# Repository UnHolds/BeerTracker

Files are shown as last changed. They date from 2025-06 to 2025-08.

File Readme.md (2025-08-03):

# Beer Tracker

This repository contains the PCB, Enclosure and Code for the Beer Tracker.

The Beer Tracker allows a group of people to keep track of
various things (mainly beer).

## What does it do?

Each person gets a tracker. If a person logs a drink then the
total amount will be synced between all peers (if in reach).
If a peer is out of reach, it will be synced later. (It can
also sync via multiple hops: eg A syncs data to B and B syncs
As data to C).

The device also allows the user to see the current counts of
the other peers.

## Why?

This is a really good question...

It all started during a music festival, where we tracked our
beer consumption with a tally sheet. This worked great, as
long as we all are together in a group. But some people have
different music taste and hence the group was split and the
tracking failed. This major problem needed to be addressed. A
smart way to solve it would be to just you a tracking app, or
to write our own app if we are really fancy. But those
solutions aren't enough overengineered!!!. Hence we created
this project.

## Structure

- `code` - source code for the ESP32
- `enclosure` - STL files and FreeCAD files of the case
- `kicad` - schematic + pcb layout

## Images

TODO

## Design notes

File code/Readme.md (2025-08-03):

# Code

Welcome to the brain section of the project.

## Config

There exists the `config.h` file. Here you can define:
- Number of users and their names
- Max username length
- Sleep time (time between auto-syncs)

The type of things to be tracked are somewhat hardcoded and can't be changed that easily. That's a bit sad, but it can't be helped. This may be changed in the future.

## Structure

- `button` - handles IO events of 1 button
- `display` - everything that is displayed and menu stuff
- `input` - handles IO (single press, double press, long press)
- `main` - inits everything and then loops
- `message` - handles the send and recv of the sync messages

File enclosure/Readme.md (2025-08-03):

# Enclosure

Welcome to the enclosure section of the beer tracker. This enclosure can be
made via a 3D printer. I recommend NOT using PLA, but rather PETG or ASA.
The enclosure will be more robust this way.

If you just want to print it and not modify it, then you can use the provided
STL files located in the `stl` folder. (Yes you need to print all 3).

If you want to modify the files you can open the projectfile (`BeerTracker.FCStd`)
with FreeCAD.

## Additional Material

- 4x M3 Screws
- 4x M3 Nuts

## 3D - Assembly

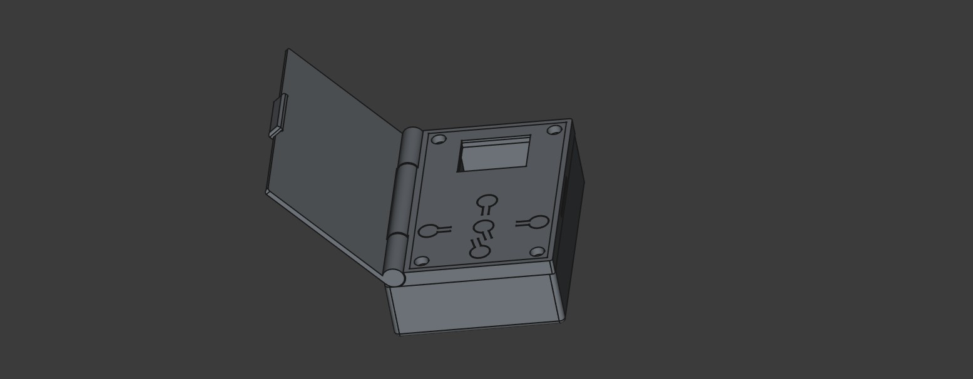
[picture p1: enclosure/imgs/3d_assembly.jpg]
Assembly of the enclosure


## How to assemble

1. Insert the button cover inside the lid.
2. Insert the nut into the case from the bottom. (Make sure that nut is oriented correctly,
    - Tip: If you have a longer M3 screw, then insert it from the top of the case and then screw on the nut. After that you can use a hammer to insert the nut from the bottom. The screw will keep the nut straight.)
3. Insert the PCB into the button cover.
4. Sandwich the two halfs
5. Done.

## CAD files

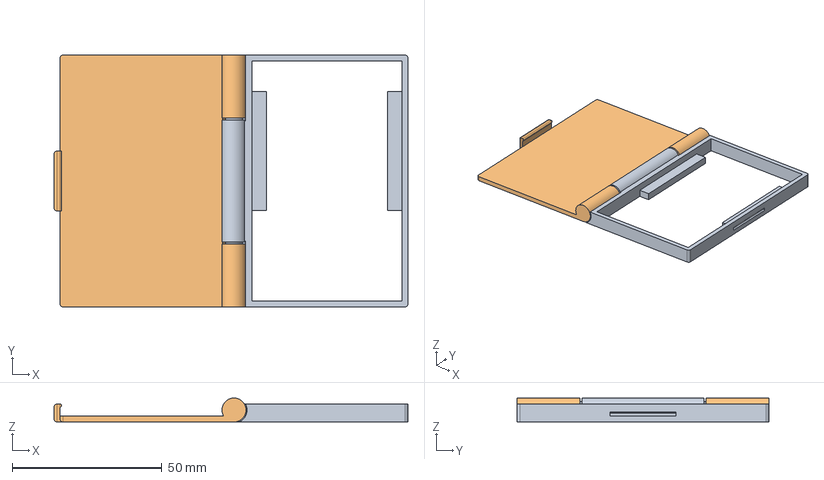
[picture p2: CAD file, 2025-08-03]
enclosure/BeerTracker.FCStd
118.0 x 84.0 x 8.00 mm
TopBottom
TopTop

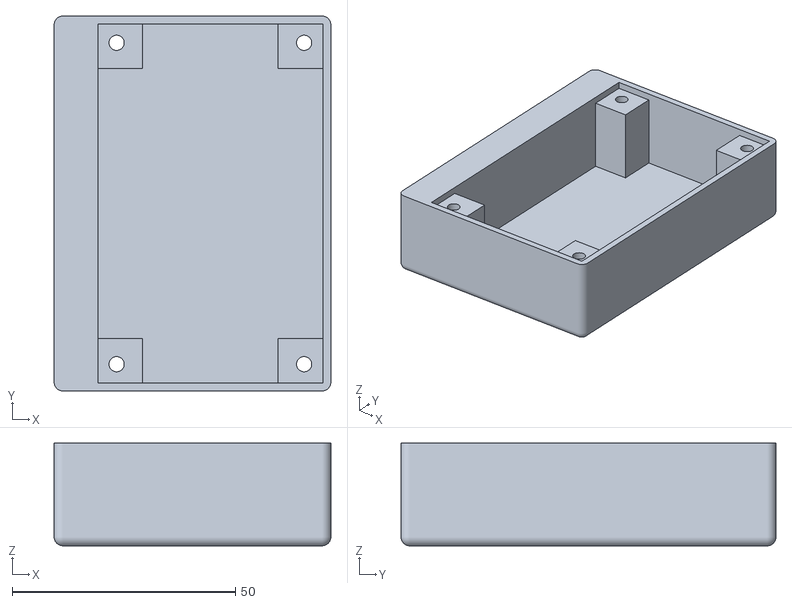
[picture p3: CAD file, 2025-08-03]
enclosure/stl/lower_case.stl
62.0 x 84.0 x 23.0

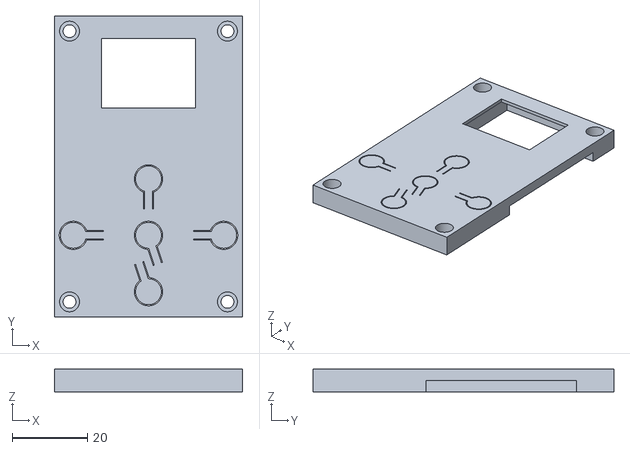
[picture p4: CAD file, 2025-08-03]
enclosure/stl/btn_cover.stl
50.0 x 80.0 x 6.00

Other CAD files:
enclosure/stl/lid.stl

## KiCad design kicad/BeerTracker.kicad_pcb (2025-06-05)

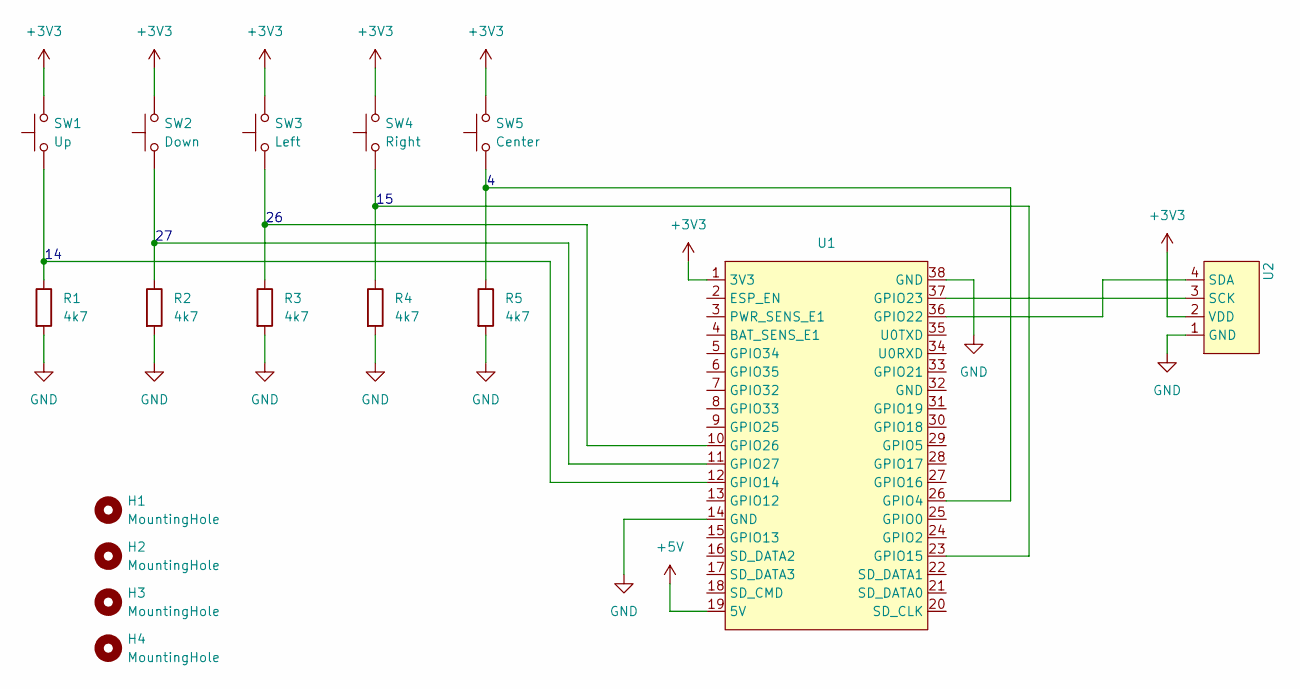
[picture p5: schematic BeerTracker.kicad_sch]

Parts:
H1, H2, H3, H4: MountingHole; MountingHole_3.2mm_M3
R1, R2, R3, R4, R5: 4k7; R_0805_2012Metric_Pad1.20x1.40mm_HandSolder
SW1: Up; SW_PUSH_6mm
SW2: Down; SW_PUSH_6mm
SW3: Left; SW_PUSH_6mm
SW4: Right; SW_PUSH_6mm
SW5: Center; SW_PUSH_6mm
U1: ESP32-DevKit-LiPo
U2: OLED

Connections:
+3V3: SW1.2, SW2.2, SW3.2, SW4.2, SW5.2, U1.1 (3V3), U2.2 (VDD)
+5V: U1.19 (5V)
GND: R1.2, R2.2, R3.2, R4.2, R5.2, U1.14 (GND), U1.38 (GND), U2.1 (GND)
unnamed: R5.1, SW5.1, U1.26 (GPIO4)
unnamed: R1.1, SW1.1, U1.12 (GPIO14)
unnamed: R4.1, SW4.1, U1.23 (GPIO15)
unnamed: U1.36 (GPIO22), U2.4 (SDA)
unnamed: U1.37 (GPIO23), U2.3 (SCK)
unnamed: R3.1, SW3.1, U1.10 (GPIO26)
unnamed: R2.1, SW2.1, U1.11 (GPIO27)

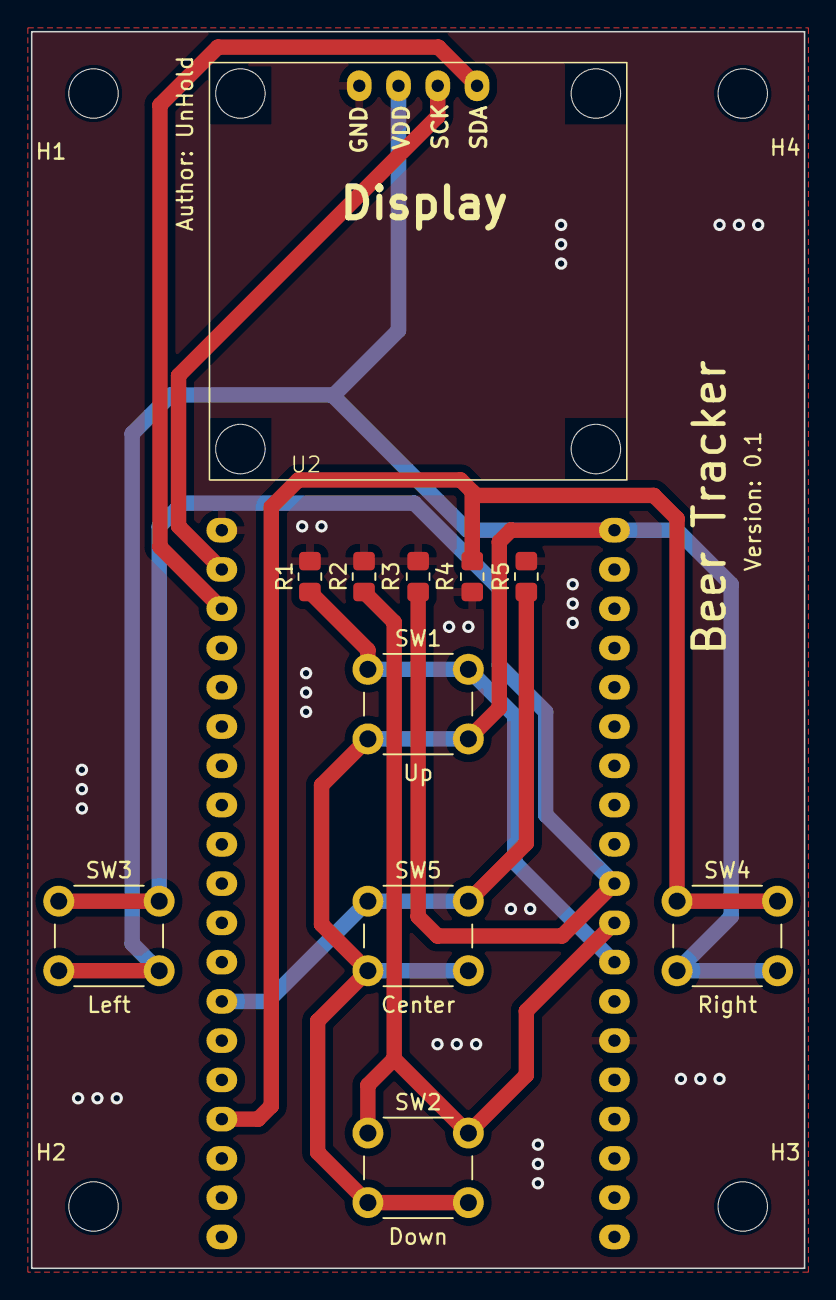
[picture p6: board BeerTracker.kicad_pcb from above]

Board: 2 copper layers, 50.0 x 80.0 mm, 16 parts (1 on the bottom side), 9 nets.

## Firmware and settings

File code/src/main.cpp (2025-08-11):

#include <Arduino.h>
#include <Wire.h>
#include <ESP32Time.h>

#include "display.h"
#include "input.h"
#include "message.h"
#include "config.h"
#include "peers.h"


#define SCREEN_WIDTH 128 // OLED display width, in pixels
#define SCREEN_HEIGHT 64// OLED display height, in pixels
#define SDA_SCREEN 22
#define SCK_SCREEN 23
#define OLED_RESET -1 // Reset pin

ESP32Time rtc(0);


Display display(SCREEN_WIDTH, SCREEN_HEIGHT, VERSION, &rtc);
Input input(14, 27, 26, 15, 4, true);

Message message;

unsigned long update_send_time = ULONG_MAX;
unsigned long update_sleep_time = ULONG_MAX;
bool timer_wakeup;
bool screen_locked = true;
int screen_lock_sequence_idx = 0;
InputType unlock_sequence[] = {InputType::LEFT, InputType::RIGHT, InputType::LEFT, InputType::RIGHT};

#ifdef DEBUG
String InputTypetoString(InputType type) {
    switch (type) {
        case InputType::UP:
            return "UP";
        case InputType::DOWN:
            return "DOWN";
        case InputType::LEFT:
            return "LEFT";
        case InputType::RIGHT:
            return "RIGHT";
        case InputType::CENTER:
            return "CENTER";
        case InputType::UP_LONG:
            return "UP_LONG";
        case InputType::DOWN_LONG:
            return "DOWN_LONG";
        case InputType::LEFT_LONG:
            return "LEFT_LONG";
        case InputType::RIGHT_LONG:
            return "RIGHT_LONG";
        case InputType::CENTER_LONG:
            return "CENTER_LONG";
        case InputType::UP_DOUBLE:
            return "UP_DOUBLE";
        case InputType::DOWN_DOUBLE:
            return "DOWN_DOUBLE";
        case InputType::LEFT_DOUBLE:
            return "LEFT_DOUBLE";
        case InputType::RIGHT_DOUBLE:
            return "RIGHT_DOUBLE";
        case InputType::CENTER_DOUBLE:
            return "CENTER_DOUBLE";
        case InputType::NONE:
            return "NONE";
        default:
            return "UNKNOWN_INPUT_TYPE"; // Fallback for any unhandled or future enum values
    }
}
#endif

void go_to_sleep() {
    long time_till_next_wakeup = SLEEP_TIME - rtc.getEpoch() % SLEEP_TIME;
    #ifdef DEBUG
    Serial.print("Timer sleeping for: ");
    Serial.println(time_till_next_wakeup);
    Serial.print("Wakeuptime: ");
    Serial.println(rtc.getEpoch() + time_till_next_wakeup);
    #endif
    esp_sleep_enable_timer_wakeup(secToUs(time_till_next_wakeup));
    display.clear();
    esp_deep_sleep_start();
}

void send_update_message() {
    #ifdef DEBUG
    Serial.println("Sending update message");
    #endif
    message.send();
}


void add_peers(){
    message.add_peers(peers, NUMBER_OF_PEERS);
}


long last_command = millis();

void handle_unlock_event(InputType t){

    if(t == unlock_sequence[screen_lock_sequence_idx]){
        screen_lock_sequence_idx++;
    }else{
        screen_lock_sequence_idx == 0;
    }

    if(screen_lock_sequence_idx == sizeof(unlock_sequence) / sizeof(unlock_sequence[0])){
        screen_locked = false;
        screen_lock_sequence_idx = 0;
    }
}

void setup() {

    screen_locked = LOCK_SCREEN_ENABLE;

    esp_sleep_wakeup_cause_t wakeup_reason = esp_sleep_get_wakeup_cause();

    Serial.begin(115200);
    Wire.begin(SDA_SCREEN, SCK_SCREEN);

    if (!LittleFS.begin(true)) {
        Serial.println("Formatting LittleFs!!");
        if (!LittleFS.begin()) {
            Serial.println("FATAL: Failed to mount LittleFS even after formatting!");
            return;
        }
    }

    input.begin();
    message.begin(&rtc);

    display.begin(&message);
    if (wakeup_reason != ESP_SLEEP_WAKEUP_TIMER){
        display.splash_screen();
    }

    add_peers();

    #ifdef DEBUG
    switch (wakeup_reason) {
        case ESP_SLEEP_WAKEUP_EXT0:
            Serial.println("Wakeup caused by external signal using RTC_IO");
        break;
        case ESP_SLEEP_WAKEUP_EXT1:
            Serial.println("Wakeup caused by external signal using RTC_CNTL");
        break;
        case ESP_SLEEP_WAKEUP_TIMER:
            Serial.println("Wakeup caused by timer");
        break;
        case ESP_SLEEP_WAKEUP_TOUCHPAD:
            Serial.println("Wakeup caused by touchpad");
        break;
        case ESP_SLEEP_WAKEUP_ULP:
            Serial.println("Wakeup caused by ULP program");
        break;
        default:
            Serial.printf("Wakeup was not caused by deep sleep: %d\n", wakeup_reason);
        break;
    }
    #endif

    if(wakeup_reason == ESP_SLEEP_WAKEUP_TIMER){
        update_send_time = millis() + (UPDATE_AWAKE_TIME - USER_SEND_OFFSET * NUM_USER) / 2 + USER_SEND_OFFSET * message.current_user_idx();
        update_sleep_time = millis() + UPDATE_AWAKE_TIME;
        timer_wakeup = true;
    }else{
        update_send_time = ULONG_MAX;
        update_sleep_time = ULONG_MAX;
        timer_wakeup = false;
    }

    #ifdef DEBUG
        Serial.print("current epoch: ");
        Serial.println(rtc.getEpoch());
    #endif

    last_command = millis();

    if(screen_locked && wakeup_reason != ESP_SLEEP_WAKEUP_TIMER) {
        display.lock_screen();
    }

    //fixes input on startup
    input.get_input();
}



void loop() {

    long current_millis = millis();
    InputType t = input.get_input();
    if(t != InputType::NONE) {
        last_command = current_millis;
        timer_wakeup = false;
        #ifdef DEBUG
        Serial.println(InputTypetoString(t));
        #endif
    }

    if(current_millis - last_command > STANDBY_TIMEOUT && update_sleep_time == ULONG_MAX){
        #ifdef DEBUG
            Serial.println("Going to sleep standby timeout");
        #endif
        go_to_sleep();
    }

    if(timer_wakeup == false){

        if(screen_locked){
            handle_unlock_event(t);
            if(screen_locked){
                //still locked return
                return;
            }
        }

        display.update(t);
    }

    //send update msg
    if(current_millis > update_send_time){
        send_update_message();
        update_send_time = ULONG_MAX;
    }

    //goto sleep
    if(current_millis > update_sleep_time){
        #ifdef DEBUG
            Serial.println("Going to sleep after update");
        #endif
        update_sleep_time == ULONG_MAX;
        go_to_sleep();
    }
}

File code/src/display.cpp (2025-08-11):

#include "display.h"

Display::Display(int width, int heigth, const char* version, ESP32Time* rtc) : display(width, heigth, &Wire, -1) {
    this->width = width;
    this->height = height;
    this->version = version;
    this->rtc = rtc;
}

void Display::begin(Message* message) {
    if(!this->display.begin(SSD1306_SWITCHCAPVCC, 0x3C)) {
        Serial.println(F("SSD1306 allocation failed"));
        for(;;);
    }
    this->display.clearDisplay();
    this->message = message;

    pinMode(BAT_PIN, INPUT);
    pinMode(PWR_PIN, INPUT);

    if((&this->message->send_message)->time > rtc->getEpoch()){
        #ifdef DEBUG
        Serial.println("updating the epoch to the time stored at esp32");
        #endif
        this->rtc->setTime((&this->message->send_message)->time, 0);
    }
}

void Display::print_x_y(String text, int x_pos, int y_pos, int text_size) {
    this->display.setTextSize(text_size);
    this->display.setTextColor(WHITE);
    this->display.setCursor(x_pos, y_pos);
    this->display.println(text);
}

void Display::print_center_x(String text, int y_pos, int text_size) {
    this->display.setTextSize(text_size);
    this->display.setTextColor(WHITE);
    this->display.setCursor((this->width / 2) - (6 * text_size * text.length() / 2), y_pos);
    this->display.println(text);
}

void Display::splash_screen() {

    this->print_center_x("Beer-Track", 10, 2);
    this->print_center_x("by @UnHold", 30, 1);
    std::string buf("Version: ");
    buf.append(this->version);
    this->print_center_x(buf.c_str(), 45, 1);

    #ifdef COMMIT_HASH
    std::string buf2("(");
    buf2.append(COMMIT_HASH);
    buf2.append(")");
    this->print_center_x(buf2.c_str(), 55, 1);
    #endif

    this->display.display();
    delay(SPLASH_SCREEN_TIME);
    this->display.clearDisplay();
    this->display.display();
}

void Display::print_battery() {
    char bat_v[6];
    float pwr = 3.3 / 4095.0 * analogRead(PWR_PIN);
    float bat = 3.3 / 4095.0 * analogRead(BAT_PIN);

    if(pwr > 2){

        this->print_x_y("PWR", this->width - 6 * 3, 0, 1);
    } else {
        this->print_icon(Icon::BAT, 128-8, 8/2);
        //snprintf (bat_v, sizeof(bat_v), "%.2fVV", bat);
        //this->print_x_y(bat_v, this->width - 6 * (sizeof(bat_v)), 0, 1);
    }
}

void Display::lock_screen(){
    this->clear();
    this->print_icon(Icon::LOCKED, 64, 20);
    this->print_center_x("To Unlock: < > < >", 42, 1);
    this->display.display();
}

void Display::print_time() {
    char time_str[32];
    // 2024-06-27 23:24:25
    sprintf(time_str, "%04d-%02d-%02d %02d:%02d:%02d", rtc->getYear(), rtc->getMonth(), rtc->getDay(), rtc->getHour(true), rtc->getMinute(), rtc->getSecond());
    this->print_center_x(time_str, 64-7, 1);
}
void Display::print_icon(Icon icon, int x_pos, int y_pos) {
    int id = static_cast<int>(icon) & 0xFF;
    int y_size = (static_cast<int>(icon) >> 8) & 0xFF;
    int x_size = (static_cast<int>(icon) >> 16) & 0xFF;
    this->display.drawBitmap(x_pos - x_size / 2, y_pos - y_size / 2, icon_array[id], x_size, y_size, WHITE);
}

void Display::update(InputType input) {
    this->display.clearDisplay();
    //print the username in the topleft
    this->print_x_y(this->message->send_message.users[this->message->send_message.user_id].name, 0, 0, 1);
    print_battery();
    print_time();


    switch(this->menu){
        case Menu::MAIN:
            this->update_main_menu(input);
        break;
        case Menu::BEER:
            this->print_center_x("Beer", 0, 1);
            this->increment_menu(input, &this->message->send_message.users[this->message->send_message.user_id].beer);
        break;
        case Menu::SHOT:
            this->print_center_x("Shot", 0, 1);
            this->increment_menu(input, &this->message->send_message.users[this->message->send_message.user_id].shots);
        break;
        case Menu::WATER:
            this->print_center_x("Water", 0, 1);
            this->increment_menu(input, &this->message->send_message.users[this->message->send_message.user_id].water);
        break;
        case Menu::SELECT_USER:
            this->print_center_x("WhoAmI", 0, 1);
            this->change_user(input);
        break;
        case Menu::RESET:
            this->reset(input);
        break;
        case Menu::SHOW_USERS:
            this->print_center_x("Users", 0, 1);
            this->show_users(input);
        break;
        case Menu::SET_TIME:
            this->print_center_x("Set Time", 0, 1);
            this->set_time(input);
        break;
    }

    this->display.display();
}

void Display::change_user(InputType input) {
    if(this->submenu_idx == -1){
        this->submenu_idx = this->message->send_message.user_id;
    }

    //safety
    this->submenu_idx = this->submenu_idx % NUM_USER;

    this->print_center_x(this->message->send_message.users[this->submenu_idx].name, 32 - 8, 2);
    this->print_x_y("<", 10, 32 - 8, 2);
    this->print_x_y(">", 110, 32 - 8, 2);

    if(input == InputType::LEFT){
        this->submenu_idx = (this->submenu_idx + NUM_USER - 1) % NUM_USER;
    }
    if(input == InputType::RIGHT){
        this->submenu_idx = (this->submenu_idx + 1) % NUM_USER;
    }
    if(input == InputType::CENTER){
        (&this->message->send_message)->user_id = this->submenu_idx;
        this->menu = Menu::MAIN;
        this->message->send();
    }
}

void Display::reset(InputType input) {
    this->print_center_x("<- Y  (RST)  N ->", 32 - 8, 1);

    if(input == InputType::LEFT){
        for(int i = 0; i < NUM_USER; i++){
            strcpy((&this->message->send_message)->users[i].name, RST_USERNAMES[i].c_str());
            (&this->message->send_message)->users[i].beer = 0;
            (&this->message->send_message)->users[i].water = 0;
            (&this->message->send_message)->users[i].shots = 0;
            (&this->message->send_message)->users[i].idx = 0;
        }
        this->menu = Menu::MAIN;
    }
    if(input == InputType::RIGHT){
        this->menu = Menu::MAIN;
    }
    rtc->setTime(1751203509); //Sun Jun 29 2025 13:25:09 GMT+0000
}

void Display::print_menu(const char* name) {
    this->print_center_x(name, 32 - 8, 2);
}

void Display::increment_menu(InputType input, uint8_t* value) {
    char num_s[4];
    sprintf(num_s, "%d", *value);
    this->print_center_x(num_s, 32 - 8, 2);
    this->print_x_y("-", 10, 32 - 8, 2);
    this->print_x_y("+", 110, 32 - 8, 2);

    if(input == InputType::LEFT){
        *value -= 1;
    }
    if(input == InputType::RIGHT){
        *value += 1;
    }
    if(input == InputType::CENTER){
        this->menu = Menu::MAIN;
        this->message->send();
    }

}
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

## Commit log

2025-06-04 fixed button read
2025-06-05 added v0.1 pcb
    [BeerTracker.kicad_pcb, BeerTracker.kicad_sch]
2025-06-29 added time support + user view + bug fixes
    [display.cpp, main.cpp, message.cpp]
2025-06-29 fixed sleep time + sleep screen + time zone
    [main.cpp, message.cpp]
2025-06-29 added basic enclousure
    [BeerTracker.FCStd]
2025-06-29 added top and spacer
    [BeerTracker-Body.stl, BeerTracker-Spacer.stl, BeerTracker-Top.stl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]
2025-08-03 removed old case
    [BeerTracker-Body.stl, BeerTracker-Spacer.stl, BeerTracker-Top.stl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]
2025-08-03 added V2 case of the beer tracker
    [BeerTracker.FCStd]
2025-08-03 added stl exports
    [btn_cover.stl, lid.stl, lower_case.stl]
2025-08-04 added better button support + added lock screen
2025-08-04 added better error msg
    [message.cpp]
2025-08-04 fixed sending to peers
    [main.cpp, message.cpp]
2025-08-11 simple fixed for 2.0 release
    [display.cpp, main.cpp]
2025-08-11 added ignore for lockscreen if wakeup timer
